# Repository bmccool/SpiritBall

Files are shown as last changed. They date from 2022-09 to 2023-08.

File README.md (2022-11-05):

---
tags: 📝️/🌱️
aliases:
  -
cssclass:
---

# TITLE: [[SpiritBall]]
---
## Demo

## Abstract
With 100 days until Christmas 2022, this project is set as a design challenge to create a Christmas decoration to be handed out as gifts, and as an excuse to learn and play with new tech toys and concepts.  This Readme is a copy of my notebook for this project.
## MOC
[[ESP32-S3]]
[[SpiritBall]]
[[KiCad]]
[[ESP Flasher]]
## Project Idea
- A Christmas ornament, or other holiday decoration in a ball form with addressable or patterned LED lighting.
- Primarily designed to be hung from a tree branch (plug in to light strand?)
- Based on [[ws812b]] LEDs.  
- Designed around multiple interlocking "leaves" and central management core.
	- See pic
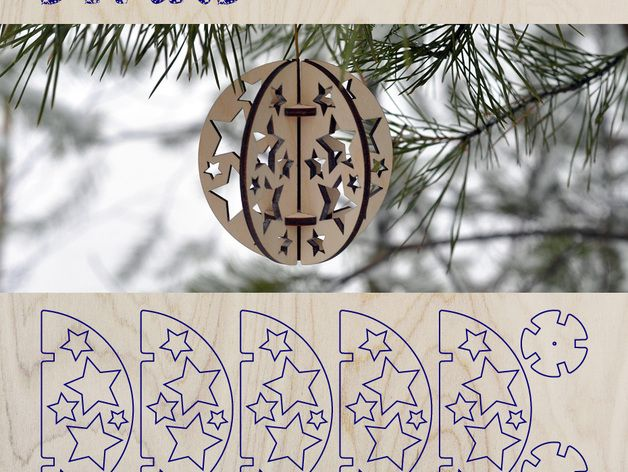
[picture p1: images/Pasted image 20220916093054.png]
		- 

## Design
### Mechanical
- Using the "multiple interlocking "leaves" strategy
	- Can we utilize card edge connectors?
	- Simpler, we could just leave the traces uncovered and solder bridge them together.
	- LEDs will be placed along the edge, firing normal to the leaf face.
		- First pass, only on one side, we can think about adding a second set on the reverse side later
		- LEDs should fire primarily in the direction of the next leaf, which should help with light diffusion
	- Do we need additional diffusion?
		- Likely not, given the LEDs will shine into the next leaf *AND* the abiliity of software to dim the LEDs, we shouldn't need mechanical diffusion
### Electrical
- Use a [[WS2812B]] [[SMD LEDs|LED]]
	- Likely this one, which I think is the same as on the ESP32-S3 Dev board
	- [WS2812B-Mini](https://jlcpcb.com/partdetail/Worldsemi-WS2812BMini/C527089)
	- Alternatively, this one which is the normal [[WS2812B]]
	- [WS2812B](https://jlcpcb.com/partdetail/Worldsemi-WS2812B_BW/C2761795)
- Control LEDs with [ESP32-S3 Module](https://jlcpcb.com/partdetail/3198296-ESP32_S3_WROOM_1N8/C2913198)
	- [Datasheet](https://www.espressif.com/sites/default/files/documentation/esp32-s3-wroom-1_wroom-1u_datasheet_en.pdf)
	- Likely need to spend some time figuring out how to use module standalone instead of on dev board
	- Can we power this from a standard christmas light strand?
		- How about a battery? 18650?
	- Technical things
		- EN/BOOT, Reset, Power On, UART/USB
			- A switch on EN would be a temporary contact to ground to reset the board, probably wanted on main board for a while
			- A siwtch on BOOT would allow the board to be reset into BOOTLOADER mode.  Which would then allow programming.  Assuming we are loading via USB/UART, which would otherwise control the EN and BOOT pins via transistors (see Automatic Bootloader for S3), we would never use this button.  Ergo, don't need it on board, we can pull a button (still not very useful) to the flash tool board to save space and parts.
			- So, onboard button for EN, no onboard button for BOOT, but we will utilize an external flash tool (usb/uart bridge) and we can stick a redundant EN button and BOOT button there.
			- In this scenario, we still need a pullup on EN.  BOOT can be left "floating" on the internal pullup.
- USB-C
	- [JLCPCB Link](https://jlcpcb.com/partdetail/Molex-1054500101/C134092)
	- [Molex Part](https://www.molex.com/molex/products/part-detail/io_connectors/1054500101)
	- [Molex Spec](https://www.molex.com/pdm_docs/ps/PS-105448-001-001.pdf)
	- USB/UART converter
### Software
## Work
- [[2022-09-26]] Created [SpiritBall Repo]() with first pass of schematic and PCB layout.  Tagging as [SpiritBall v0.1.0]()  This is intended as a minimum viable product with only a single plane of LEDs.  I still need to create board gerber files and run them through [[JLCPCB]] online tools to check for compatibility, as well as generate a BOM and place the order.
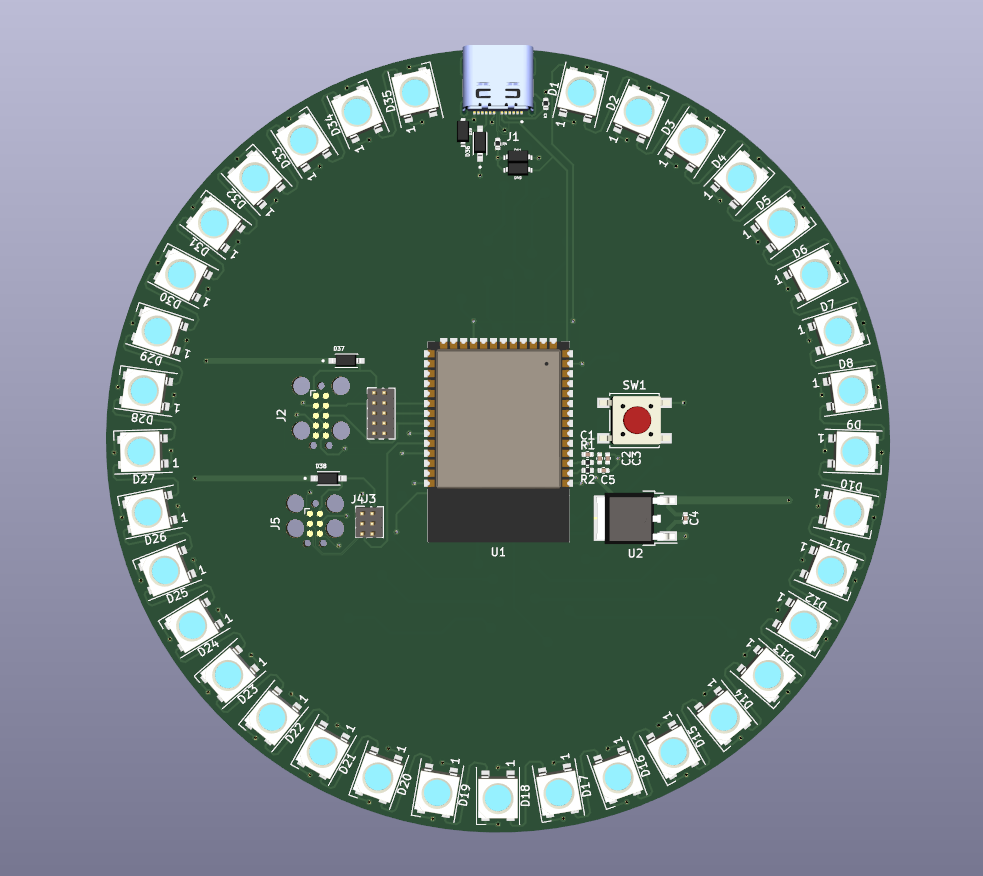
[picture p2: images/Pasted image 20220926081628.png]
	- 
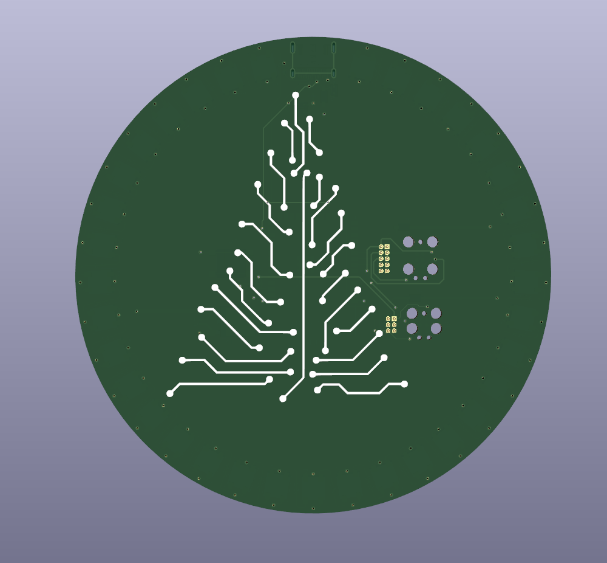
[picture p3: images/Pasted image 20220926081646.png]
	- 
- [[2022-11-01]] - Success!  The first batch of 5 assembled boards came back last week (I had done some minor tocuch up work, swapped some parts for in-stock, etc).  I also used a [[ESP-Prog]] flash board to get things started, though I think I could eventually use the USB cable or even [[OTA]] updates.  **TODO** add pictures and video.  Re: software, I've been turned onto using [[RMT]] for controlling the LEDs by [[@Chris Lomont]], and it was a cinch to get up and running a simple rainbow chase.  Now the fun part - Making it look more appealing and less like rainbow unicorn vomit :) 
	- PS: Had a brief moment of panic - Playing with some LED patterns and decided to pull back the brightness so it didn't hurt my eyes.  I lowered the SATURATION when I meant to lower the VALUE in the HVS color representation.  This of course just made all the LEDs white, and full brightness, which spiked current draw up over 700mA.  Oops.  But the program runs at boot, and is powered through the PROG interface meant there wasn't enough power available to flash through UART.  Turns out the USB port on the [[SpiritBall]] works fine to power the board with some extra power.  Plugged in both USB and PROG interface (which saw maybe 10mA draw) and recovered the board.  I'm pretty happy with how this first revision is performing.
	- Also, had to shake off some rust to get example code up and running.  Here's what I did:
		```
		cd C:\projects\brendon\ESP32S3-Project-Template
		xcopy /e /i C:\Espressif\frameworks\esp-idf-v5.0\examples\get-started\hello_world ./
		idf.py set-target esp32s3
		(remove build dir if it complains)
		idf.py -p COM5 flash monitor
		```
- [[2022-11-05]] - I've been experimenting with different patterns and have got to the point I have things worth saving.  So I'm spending some time to update github.  Also switched over to C++ for most things, but I kept the [[RMT]] encoder in C because I didn't feel like re-writing it and it works well enough as is... Maybe that's a task for a later date.  Things I still need to do:
	- [ ] Settle on a handful of set patterns (including `OFF`)
	- [ ] Cycle through set patterns with onboard buttons
	- [ ] Add some sort of software over-current protection
	- [ ] Update via USB-C cable
	- [ ] Update via OTA (stretch)
	- [ ] Control patterns via BT or WiFi (stretch)

/Work
# ./[[SpiritBall]]
---

Tags: [[ESP32-S3]]

Reference:

Related:

Created: [[2022-09-16]]

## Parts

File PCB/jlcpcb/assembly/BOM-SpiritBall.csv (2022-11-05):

Comment | Designator | Footprint | LCSC
105450-0101 | J1 | USB_C_MOLEX_105450-0101 | C134092
LESD5Z5.0CT1G | D39,D40,D41 | D_SOD-523 | C136167
0.1uF | C3 | C_0402_1005Metric | C1525
10uF | C2,C4 | C_0402_1005Metric | C15525
0k | R2 | R_0402_1005Metric | C17168
10K | R1,R5 | R_0402_1005Metric | C25744
5.1k | R3,R4 | R_0402_1005Metric | C25905
WS2812B | D1,D10,D11,D12,D13,D14,D15,D16,D17,D18,D19,D2,D20,D21,D22,D23,D24,D25,D26,D27,D28,D29,D3,D30,D31,D32,D33,D34,D35,D4,D5,D6,D7,D8,D9 | LED_WS2812B_PLCC4_5.0x5.0mm_P3.2mm | C2843785
ESP32-S3-WROOM-1 | U1 | ESP32-S3-WROOM-1 | C2913204
TS-1187A-B-A-B | SW1,SW2 | SW_TS-1187A-B-A-B | C318884
22uF | C5 | C_0402_1005Metric | C415703
AZ1117CD-3.3TRG1 | U2 | TO-252-2 | C460427
1uF | C1 | C_0402_1005Metric | C52923
1N5819HW-7-F | D36,D37,D38 | D_SOD-123 | C82544
1000uF | C6 | C_Elec_8x10.2 | C99833
TAG_CONNECT_DBG | J5 | Tag-Connect_TC2030-IDC-FP_2x03_P1.27mm_Vertical
TAG_CONNECT_JTAG | J2 | Tag-Connect_TC2050-IDC-FP_2x05_P1.27mm_Vertical
HEADER_DBG | J3 | PinHeader_2x03_P1.27mm_Vertical
HEADER_JTAG | J4 | PinHeader_2x05_P1.27mm_Vertical

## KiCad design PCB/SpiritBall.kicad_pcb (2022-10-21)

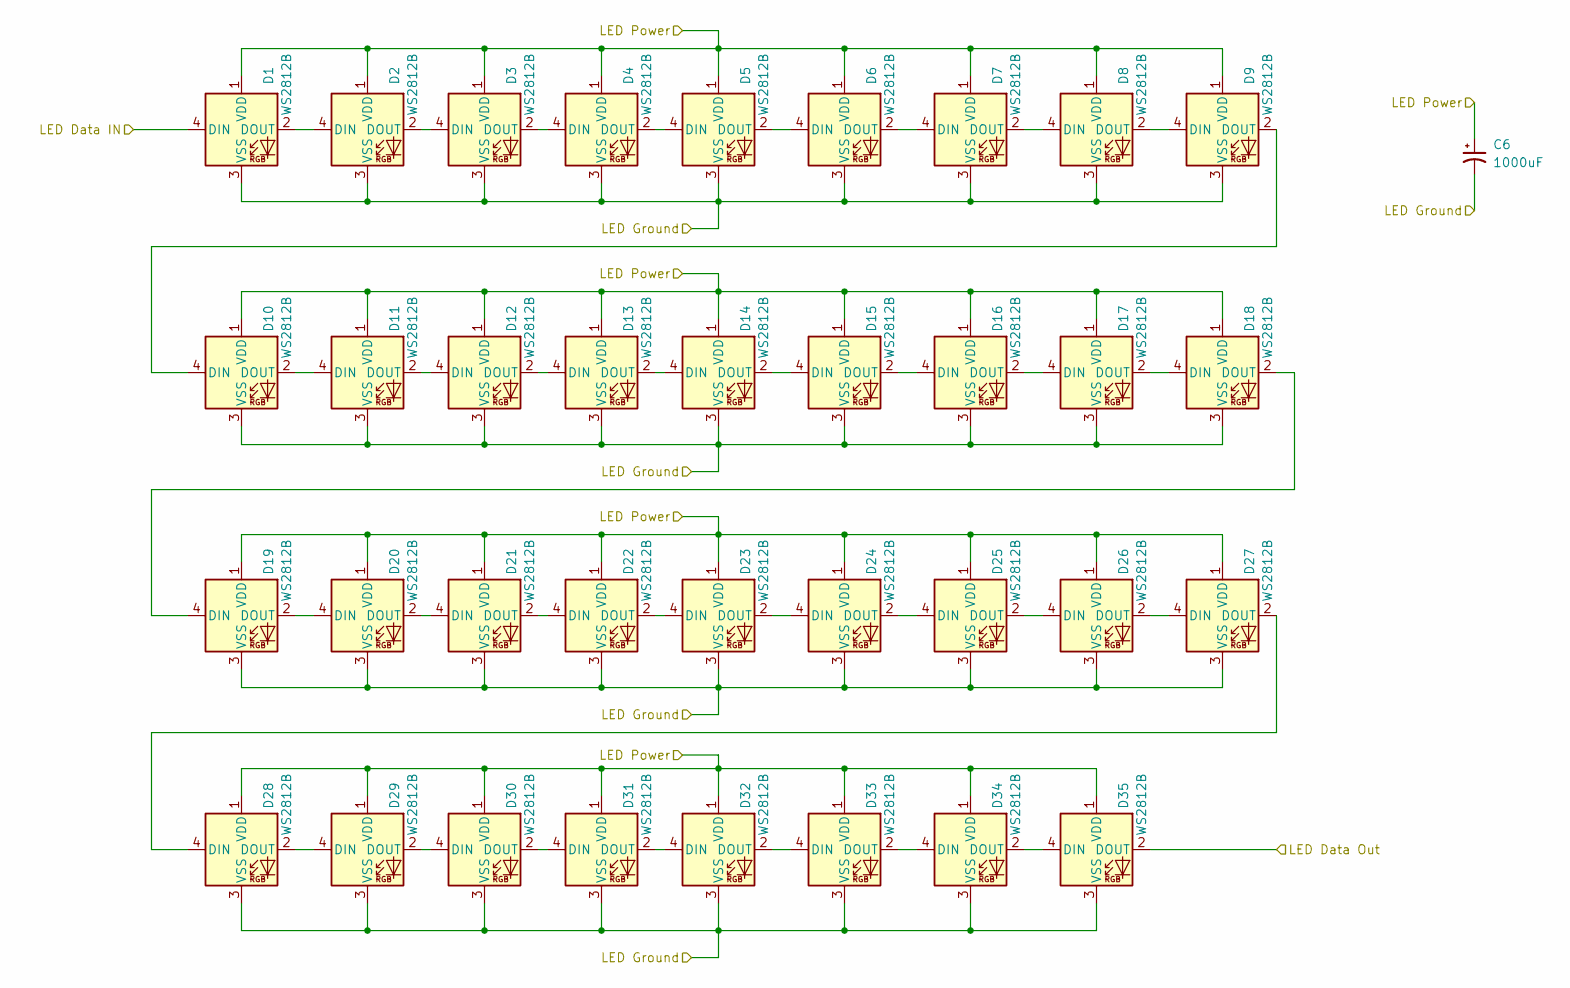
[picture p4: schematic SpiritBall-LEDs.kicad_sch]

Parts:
C6: 1000uF; C_Elec_8x10.2
D1, D2, D3, D4, D5, D6, D7, D8, D9, D10, D11, D12, D13, D14, D15, D16, D17, D18, D19, D20, D21, D22, D23, D24, D25, D26, D27, D28, D29, D30, D31, D32, D33, D34, D35: WS2812B; LED_WS2812B_PLCC4_5.0x5.0mm_P3.2mm

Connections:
+5V: C6.1, D1.1 (VDD), D2.1 (VDD), D3.1 (VDD), D4.1 (VDD), D5.1 (VDD), D6.1 (VDD), D7.1 (VDD), D8.1 (VDD), D9.1 (VDD), D10.1 (VDD), D11.1 (VDD), D12.1 (VDD), D13.1 (VDD), D14.1 (VDD), D15.1 (VDD), D16.1 (VDD), D17.1 (VDD), D18.1 (VDD), D19.1 (VDD), D20.1 (VDD), D21.1 (VDD), D22.1 (VDD), D23.1 (VDD), D24.1 (VDD), D25.1 (VDD), D26.1 (VDD), D27.1 (VDD), D28.1 (VDD), D29.1 (VDD), D30.1 (VDD), D31.1 (VDD), D32.1 (VDD), D33.1 (VDD), D34.1 (VDD), D35.1 (VDD); also elsewhere on the board
/ESP32-S3/LED Data: D1.4 (DIN); also elsewhere on the board
/LEDs/LED Data Out: D35.2 (DOUT)
GND: C6.2, D1.3 (VSS), D2.3 (VSS), D3.3 (VSS), D4.3 (VSS), D5.3 (VSS), D6.3 (VSS), D7.3 (VSS), D8.3 (VSS), D9.3 (VSS), D10.3 (VSS), D11.3 (VSS), D12.3 (VSS), D13.3 (VSS), D14.3 (VSS), D15.3 (VSS), D16.3 (VSS), D17.3 (VSS), D18.3 (VSS), D19.3 (VSS), D20.3 (VSS), D21.3 (VSS), D22.3 (VSS), D23.3 (VSS), D24.3 (VSS), D25.3 (VSS), D26.3 (VSS), D27.3 (VSS), D28.3 (VSS), D29.3 (VSS), D30.3 (VSS), D31.3 (VSS), D32.3 (VSS), D33.3 (VSS), D34.3 (VSS), D35.3 (VSS); also elsewhere on the board
unnamed: D1.2 (DOUT), D2.4 (DIN)
unnamed: D2.2 (DOUT), D3.4 (DIN)
unnamed: D3.2 (DOUT), D4.4 (DIN)
unnamed: D4.2 (DOUT), D5.4 (DIN)
unnamed: D5.2 (DOUT), D6.4 (DIN)
unnamed: D6.2 (DOUT), D7.4 (DIN)
unnamed: D7.2 (DOUT), D8.4 (DIN)
unnamed: D8.2 (DOUT), D9.4 (DIN)
unnamed: D10.2 (DOUT), D11.4 (DIN)
unnamed: D9.2 (DOUT), D10.4 (DIN)
unnamed: D11.2 (DOUT), D12.4 (DIN)
unnamed: D12.2 (DOUT), D13.4 (DIN)
unnamed: D13.2 (DOUT), D14.4 (DIN)
unnamed: D14.2 (DOUT), D15.4 (DIN)
unnamed: D15.2 (DOUT), D16.4 (DIN)
unnamed: D16.2 (DOUT), D17.4 (DIN)
unnamed: D17.2 (DOUT), D18.4 (DIN)
unnamed: D18.2 (DOUT), D19.4 (DIN)
unnamed: D19.2 (DOUT), D20.4 (DIN)
unnamed: D20.2 (DOUT), D21.4 (DIN)
unnamed: D21.2 (DOUT), D22.4 (DIN)
unnamed: D22.2 (DOUT), D23.4 (DIN)
unnamed: D23.2 (DOUT), D24.4 (DIN)
unnamed: D24.2 (DOUT), D25.4 (DIN)
unnamed: D25.2 (DOUT), D26.4 (DIN)
unnamed: D26.2 (DOUT), D27.4 (DIN)
unnamed: D27.2 (DOUT), D28.4 (DIN)
unnamed: D28.2 (DOUT), D29.4 (DIN)
unnamed: D29.2 (DOUT), D30.4 (DIN)
unnamed: D30.2 (DOUT), D31.4 (DIN)
unnamed: D31.2 (DOUT), D32.4 (DIN)
unnamed: D32.2 (DOUT), D33.4 (DIN)
unnamed: D33.2 (DOUT), D34.4 (DIN)
unnamed: D34.2 (DOUT), D35.4 (DIN)

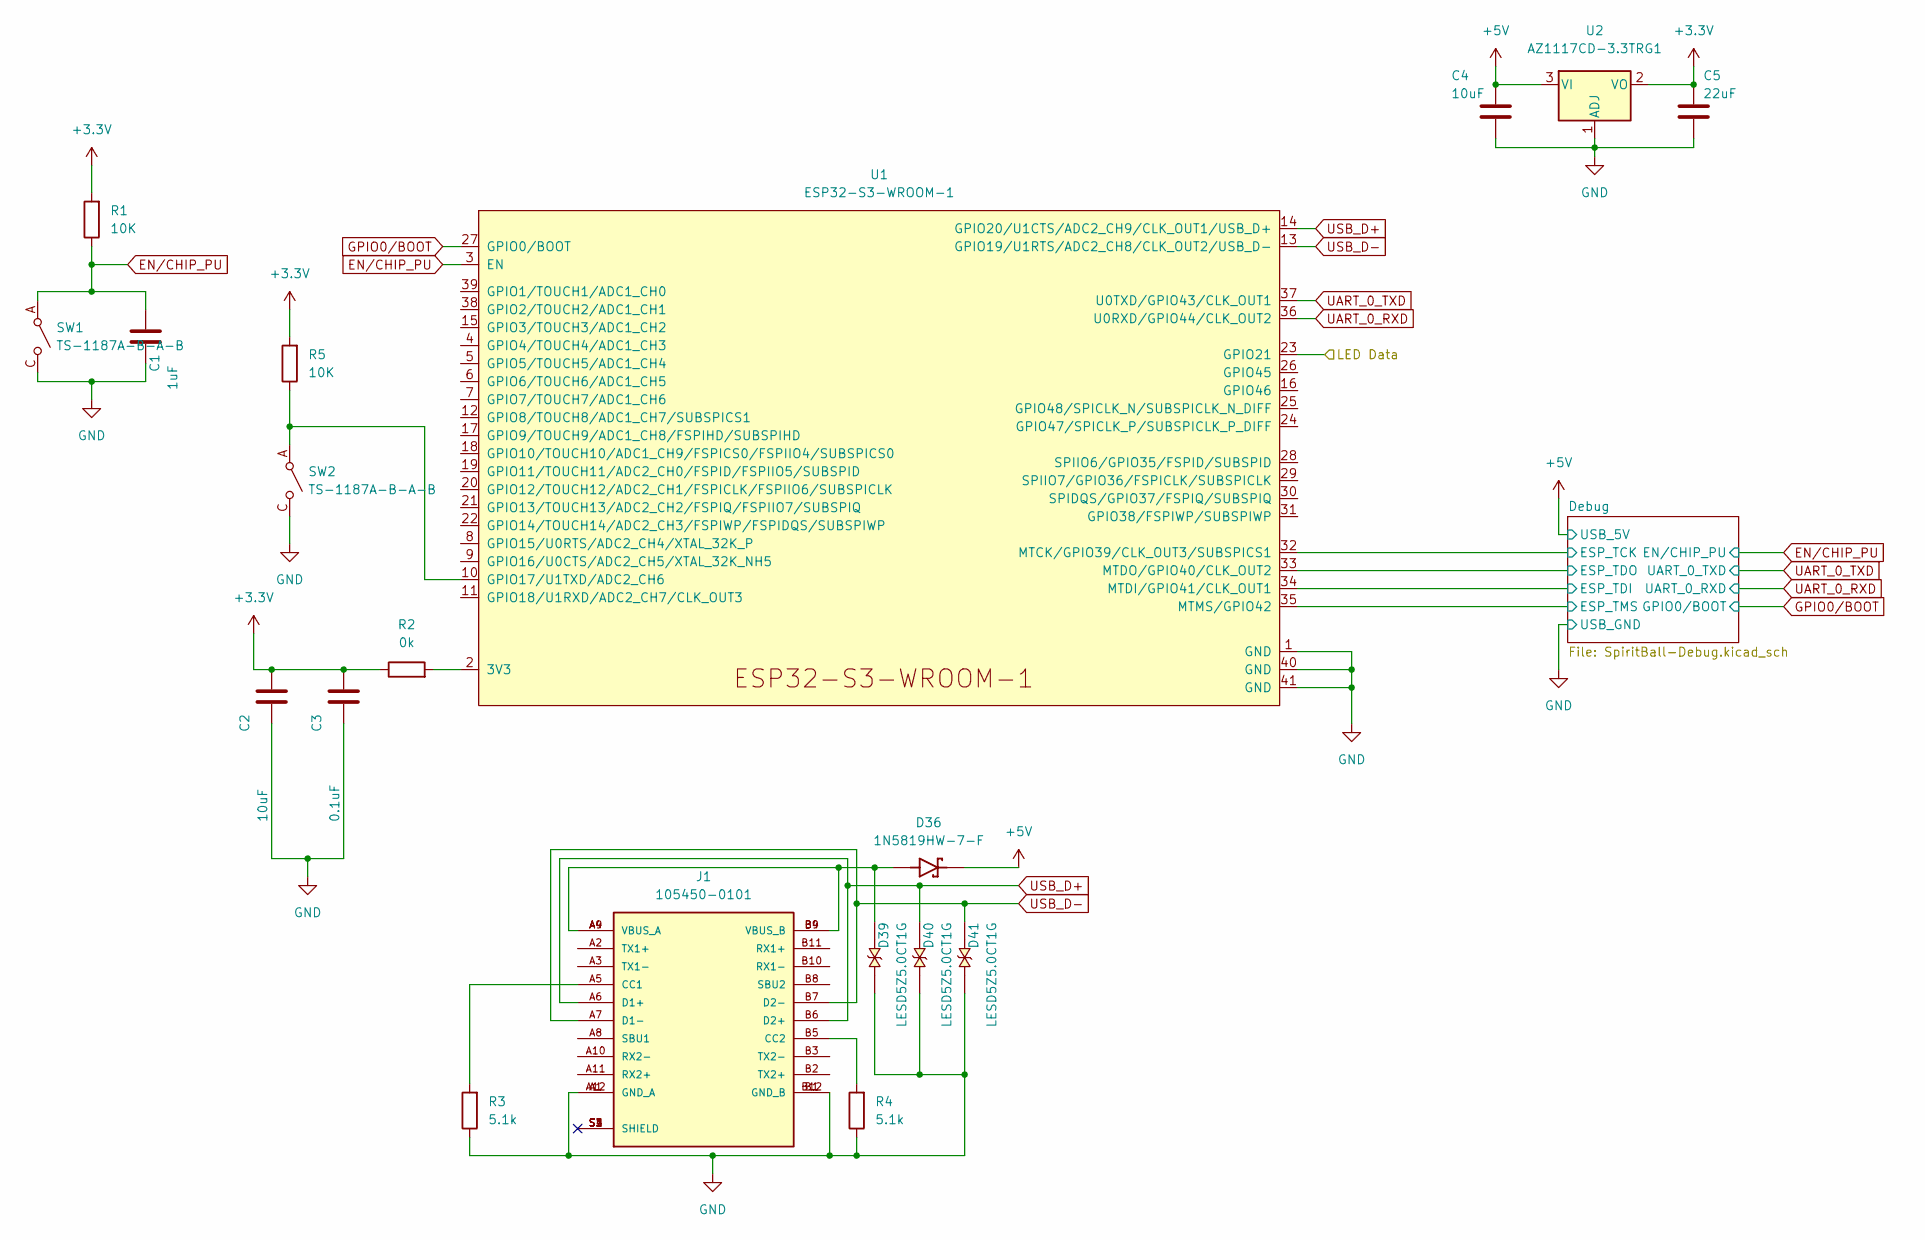
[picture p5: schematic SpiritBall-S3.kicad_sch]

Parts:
C1: 1uF; C_0402_1005Metric
C2, C4: 10uF; C_0402_1005Metric
C3: 0.1uF; C_0402_1005Metric
C5: 22uF; C_0402_1005Metric
D36: 1N5819HW-7-F; D_SOD-123; PARTREV 18-2
D39, D40, D41: LESD5Z5.0CT1G; D_SOD-523; PARTREV O
J1: 105450-0101; USB_C_MOLEX_105450-0101; PARTREV A7
R1, R5: 10K; R_0402_1005Metric
R2: 0k; R_0402_1005Metric
R3, R4: 5.1k; R_0402_1005Metric
SW1, SW2: TS-1187A-B-A-B; SW_TS-1187A-B-A-B
U1: ESP32-S3-WROOM-1
U2: AZ1117CD-3.3TRG1; TO-252-2

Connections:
+3.3V: C2.1, C3.1, C5.1, R1.2, R2.1, R5.2, U2.2 (VO)
+5V: C4.1, D36.1, U2.3 (VI); also elsewhere on the board
/ESP32-S3/Debug/ESP_TCK: U1.32 (MTCK/GPIO39/CLK_OUT3/SUBSPICS1); also elsewhere on the board
/ESP32-S3/Debug/ESP_TDI: U1.34 (MTDI/GPIO41/CLK_OUT1); also elsewhere on the board
/ESP32-S3/Debug/ESP_TDO: U1.33 (MTDO/GPIO40/CLK_OUT2); also elsewhere on the board
/ESP32-S3/Debug/ESP_TMS: U1.35 (MTMS/GPIO42); also elsewhere on the board
/ESP32-S3/LED Data: U1.23 (GPIO21); also elsewhere on the board
EN/CHIP_PU: C1.1, R1.1, SW1.A, SW1.B, U1.3 (EN); also elsewhere on the board
GND: C1.2, C2.2, C3.2, C4.2, C5.2, D39.1, D40.1, D41.1, J1.A1 (GND_A), J1.A12 (GND_A), J1.B1 (GND_B), J1.B12 (GND_B), R3.1, R4.1, SW1.C, SW1.D, SW2.C, SW2.D, U1.1 (GND), U1.40 (GND), U1.41 (GND), U2.1 (ADJ); also elsewhere on the board
GPIO0/BOOT: U1.27 (GPIO0/BOOT); also elsewhere on the board
unnamed: D36.2, D39.2, J1.A4 (VBUS_A), J1.A9 (VBUS_A), J1.B4 (VBUS_B), J1.B9 (VBUS_B)
unnamed: J1.A5 (CC1), R3.2
unnamed: J1.B5 (CC2), R4.2
unnamed: R2.2, U1.2 (3V3)
unnamed: R5.1, SW2.A, SW2.B, U1.10 (GPIO17/U1TXD/ADC2_CH6)
UART_0_RXD: U1.36 (U0RXD/GPIO44/CLK_OUT2); also elsewhere on the board
UART_0_TXD: U1.37 (U0TXD/GPIO43/CLK_OUT1); also elsewhere on the board
USB_D+: D40.2, J1.A6 (D1+), J1.B6 (D2+), U1.14 (GPIO20/U1CTS/ADC2_CH9/CLK_OUT1/USB_D+)
USB_D-: D41.2, J1.A7 (D1-), J1.B7 (D2-), U1.13 (GPIO19/U1RTS/ADC2_CH8/CLK_OUT2/USB_D-)

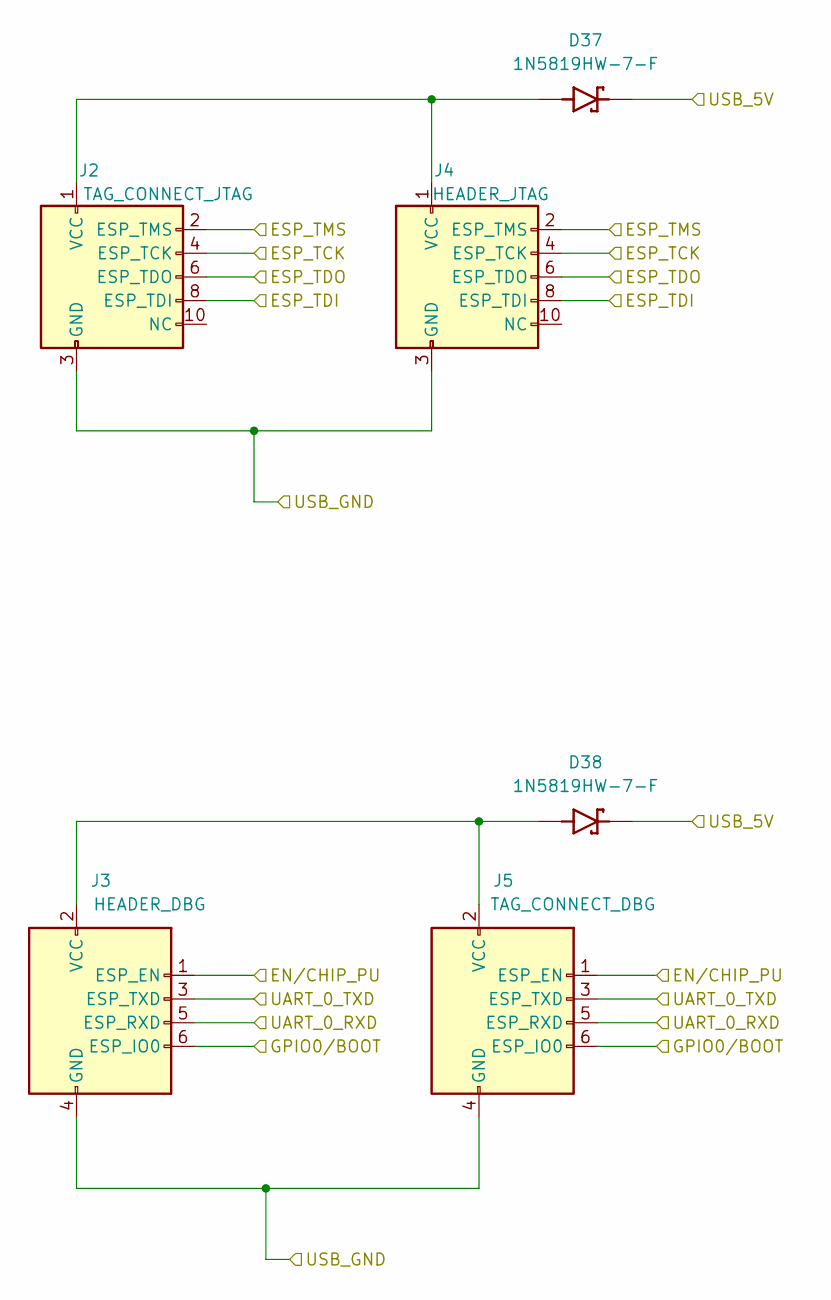
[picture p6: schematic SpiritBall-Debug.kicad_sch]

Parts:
D37, D38: 1N5819HW-7-F; D_SOD-123; PARTREV 18-2
J2: TAG_CONNECT_JTAG; Tag-Connect_TC2050-IDC-FP_2x05_P1.27mm_Vertical
J3: HEADER_DBG; PinHeader_2x03_P1.27mm_Vertical
J4: HEADER_JTAG; PinHeader_2x05_P1.27mm_Vertical
J5: TAG_CONNECT_DBG; Tag-Connect_TC2030-IDC-FP_2x03_P1.27mm_Vertical

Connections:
+5V: D37.1, D38.1; also elsewhere on the board
/ESP32-S3/Debug/ESP_TCK: J2.4 (ESP_TCK), J4.4 (ESP_TCK); also elsewhere on the board
/ESP32-S3/Debug/ESP_TDI: J2.8 (ESP_TDI), J4.8 (ESP_TDI); also elsewhere on the board
/ESP32-S3/Debug/ESP_TDO: J2.6 (ESP_TDO), J4.6 (ESP_TDO); also elsewhere on the board
/ESP32-S3/Debug/ESP_TMS: J2.2 (ESP_TMS), J4.2 (ESP_TMS); also elsewhere on the board
EN/CHIP_PU: J3.1 (ESP_EN), J5.1 (ESP_EN); also elsewhere on the board
GND: J2.3 (GND), J2.5 (GND), J2.7 (GND), J2.9 (GND), J3.4 (GND), J4.3 (GND), J4.5 (GND), J4.7 (GND), J4.9 (GND), J5.4 (GND); also elsewhere on the board
GPIO0/BOOT: J3.6 (ESP_IO0), J5.6 (ESP_IO0); also elsewhere on the board
unnamed: D37.2, J2.1 (VCC), J4.1 (VCC)
unnamed: D38.2, J3.2 (VCC), J5.2 (VCC)
UART_0_RXD: J3.5 (ESP_RXD), J5.5 (ESP_RXD); also elsewhere on the board
UART_0_TXD: J3.3 (ESP_TXD), J5.3 (ESP_TXD); also elsewhere on the board

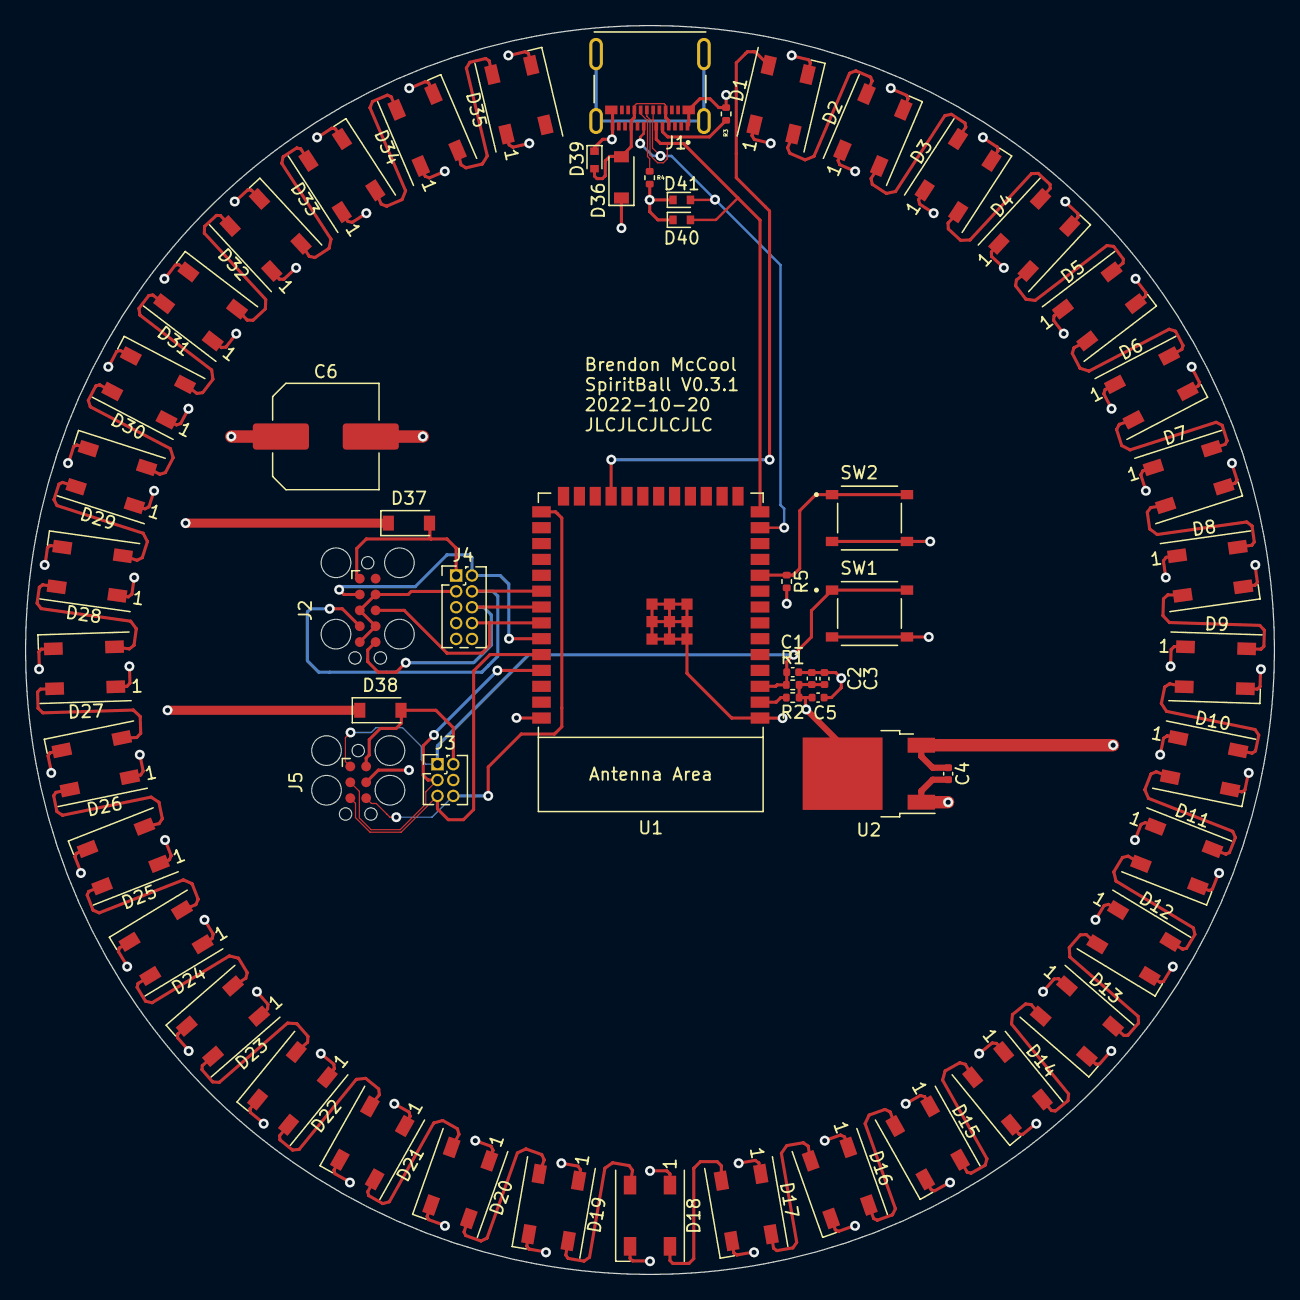
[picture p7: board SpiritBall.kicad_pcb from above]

Board: 4 copper layers, 100.0 x 100.0 mm, 61 parts (0 on the bottom side), 55 nets.

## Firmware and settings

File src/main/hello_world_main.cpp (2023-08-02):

/*
 * SPDX-FileCopyrightText: 2010-2022 Espressif Systems (Shanghai) CO LTD
 *
 * SPDX-License-Identifier: CC0-1.0
 */

#include <stdio.h>
#include <iostream> // cin, cout
#include <string.h> /* memset */
#include "sdkconfig.h"
#include "freertos/FreeRTOS.h"
#include "freertos/task.h"
#include "freertos/queue.h" // QueueHandle_t
#include "esp_chip_info.h"
#include "esp_flash.h"
#include "driver/rmt_tx.h"
#include "driver/gpio.h"

#include "led/led_strip_encoder.h"
#include "McCoolLEDs.hpp"


//#include "McCoolLEDs.h"


#define RMT_LED_STRIP_RESOLUTION_HZ 10000000 // 10MHz resolution, 1 tick = 0.1us (led strip needs a high resolution)
#define RMT_LED_STRIP_GPIO_NUM      (gpio_num_t)21
#define GPIO_INPUT_BUTTON_SW2       (gpio_num_t)17
#define GPIO_INPUT_PIN_SEL  ((1ULL<<GPIO_INPUT_BUTTON_SW2))

#define EXAMPLE_LED_NUMBERS         35
#define EXAMPLE_CHASE_SPEED_MS      10
#define ESP_INTR_FLAG_DEFAULT       0
#define NUM_PATTERNS                5
static const char *TAG = "example";

#include "esp_check.h"

extern "C" {
    void app_main();
}

static int loop_state = 0;


static uint8_t led_strip_pixels[EXAMPLE_LED_NUMBERS * 3];

void glow_random(rmt_channel_handle_t channel, rmt_encoder_t *encoder, const rmt_transmit_config_t *config){
    //uint16_t speed_ms = 100;
    McCoolLEDClump clump(channel, encoder, config, 35);
    ESP_LOGI(TAG, "Start LED Glow Random with CLUMP");
    while (1) {
        //std::cout << "clump.glow_random()" << std::endl;
        clump.glow_random_2(10, 10, 100); // Flush RGB values to LEDs
        //vTaskDelay(pdMS_TO_TICKS(speed_ms));
        vTaskDelay(pdMS_TO_TICKS(100));
    }
}

void pattern_loop(rmt_channel_handle_t channel, rmt_encoder_t *encoder, const rmt_transmit_config_t *config){
    //uint16_t speed_ms = 100;
    McCoolLEDClump clump(channel, encoder, config, 35);
    ESP_LOGI(TAG, "Starting Pattern Loop with CLUMP");

    //int pattern = 1;
    while (1) {
        switch(loop_state){
            case 3:
                clump.glow_random_2(10, 10, 100);
                vTaskDelay(pdMS_TO_TICKS(100)); // 0 for no delay, still needed to reschedule
                break;
            case 1:
                clump.rainbow_chase();
                vTaskDelay(pdMS_TO_TICKS(0)); // 0 for no delay, still needed to reschedule
                break;
            case 2:
                clump.glow_as_one(35, 10, 100);
                vTaskDelay(pdMS_TO_TICKS(100)); // 0 for no delay, still needed to reschedule
                break;
            case 5:
                clump.chase(1, 3);
                vTaskDelay(pdMS_TO_TICKS(40)); // 0 for no delay, still needed to reschedule
                break;
            case 4:
                clump.chase_colorized(2, 4, christmas);
                vTaskDelay(pdMS_TO_TICKS(40)); // 0 for no delay, still needed to reschedule
                break;
            case 0:
                clump.glow_tranistion_naive(christmas);
                vTaskDelay(pdMS_TO_TICKS(10)); // 0 for no delay, still needed to reschedule
                break;
            default:
                if (loop_state >= 100){
                    std::cout << "Resetting Loop" << std::endl;
                    clump.reset();
                    loop_state -= 100;
                }
                if (loop_state < 0){ loop_state = 0; }
                break;
        }
        
    }
}

//// GPIO
static QueueHandle_t gpio_evt_queue = NULL;

static void IRAM_ATTR gpio_isr_handler(void* arg)
{
    uint32_t gpio_num = (uint32_t) arg;
    xQueueSendFromISR(gpio_evt_queue, &gpio_num, NULL);
}

static void gpio_task(void* arg)
{
    uint32_t io_num;
    for(;;) {
        if(xQueueReceive(gpio_evt_queue, &io_num, portMAX_DELAY)) {
            if (gpio_get_level((gpio_num_t)io_num) == 1){
                loop_state += 1;
                if (loop_state > NUM_PATTERNS){
                    loop_state = 0;
                }
                // 100 signifies need to reset TODO make this a state machine please!
                if (loop_state < 100){
                    loop_state += 100;
                }
            }
            std::cout << "GPIO[" << io_num << "] interrupt, value: " << gpio_get_level((gpio_num_t)io_num) << ",  loop_state = " << loop_state << std::endl;
        }
    }
}

void setup_gpio_inputs(uint64_t pin_sel){
    //zero-initialize the config structure.
    gpio_config_t io_conf = {};

    //interrupt of rising edge
    io_conf.intr_type = GPIO_INTR_ANYEDGE;
    //bit mask of the pins
    io_conf.pin_bit_mask = pin_sel;
    //set as input mode
    io_conf.mode = GPIO_MODE_INPUT;
    //disable pull-up mode
    io_conf.pull_up_en = GPIO_PULLUP_DISABLE;
    //disable pull-down mode
    io_conf.pull_down_en = GPIO_PULLDOWN_DISABLE;
    gpio_config(&io_conf);

    //create a queue to handle gpio event from isr
    gpio_evt_queue = xQueueCreate(10, sizeof(uint32_t));
    //start gpio task
    xTaskCreate(gpio_task, "gpio_task", 2048, NULL, 10, NULL);

    //install gpio isr service
    gpio_install_isr_service(ESP_INTR_FLAG_DEFAULT);
    //hook isr handler for specific gpio pin
    gpio_isr_handler_add(GPIO_INPUT_BUTTON_SW2, gpio_isr_handler, (void*) GPIO_INPUT_BUTTON_SW2);
    //remove isr handler for gpio number.
    //gpio_isr_handler_remove(GPIO_INPUT_IO_0);
}

/// END GPIO

void app_main(void)
{

    ESP_LOGI(TAG, "Setting up GPIO");
    setup_gpio_inputs(GPIO_INPUT_PIN_SEL);

    ESP_LOGI(TAG, "Create RMT TX channel");
    rmt_channel_handle_t led_chan = NULL;
    rmt_tx_channel_config_t tx_chan_config = {
        .gpio_num = RMT_LED_STRIP_GPIO_NUM,
        .clk_src = RMT_CLK_SRC_DEFAULT, // select source clock
        .resolution_hz = RMT_LED_STRIP_RESOLUTION_HZ,
        .mem_block_symbols = 64, // increase the block size can make the LED less flickering
        .trans_queue_depth = 4, // set the number of transactions that can be pending in the background
        .flags = { 0, 0, 0, 0 }
    };
    ESP_ERROR_CHECK(rmt_new_tx_channel(&tx_chan_config, &led_chan));

    ESP_LOGI(TAG, "Install led strip encoder");
    rmt_encoder_handle_t led_encoder = NULL;
    led_strip_encoder_config_t encoder_config = {
        .resolution = RMT_LED_STRIP_RESOLUTION_HZ,
    };
    ESP_ERROR_CHECK(rmt_new_led_strip_encoder(&encoder_config, &led_encoder));

    ESP_LOGI(TAG, "Enable RMT TX channel");
    ESP_ERROR_CHECK(rmt_enable(led_chan));

    rmt_transmit_config_t tx_config = {
        .loop_count = 0, // no transfer loop
        .flags = { 0 }
    };

    //chase(led_chan, led_encoder, &tx_config);
    //line(led_chan, led_encoder, &tx_config);
    //glow_as_one(led_chan, led_encoder, &tx_config);
    //glow_random(led_chan, led_encoder, &tx_config);
    pattern_loop(led_chan, led_encoder, &tx_config);

    printf("Hello world!\n");

    /* Print chip information */
    esp_chip_info_t chip_info;
    uint32_t flash_size;
    esp_chip_info(&chip_info);
    printf("This is %s chip with %d CPU core(s), WiFi%s%s, ",
           CONFIG_IDF_TARGET,
           chip_info.cores,
           (chip_info.features & CHIP_FEATURE_BT) ? "/BT" : "",
           (chip_info.features & CHIP_FEATURE_BLE) ? "/BLE" : "");

    printf("silicon revision %d, ", chip_info.revision);
    if(esp_flash_get_size(NULL, &flash_size) != ESP_OK) {
        printf("Get flash size failed");
        return;
    }

    printf("%uMB %s flash\n", flash_size / (1024 * 1024),
           (chip_info.features & CHIP_FEATURE_EMB_FLASH) ? "embedded" : "external");

    printf("Minimum free heap size: %d bytes\n", esp_get_minimum_free_heap_size());

    for (int i = 10; i >= 0; i--) {
        printf("Restarting in %d seconds...\n", i);
        vTaskDelay(1000 / portTICK_PERIOD_MS);
    }
    printf("Restarting now.\n");
    fflush(stdout);
    esp_restart();
}

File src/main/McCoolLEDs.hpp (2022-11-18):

#pragma once
#include <stdint.h>
#include <cstdlib> // rand
#include <vector> // std::vector
#include <string.h> /* memset */
#include <iostream> // cin, cout
#include "driver/rmt_tx.h" // TODO/ I'd rather this file not know about the driver implementation...
#include <set>

// COLOR DEFINES
#define BLUE {0, 100, 0}         // 360/0 Blue
#define CYAN {60, 100, 0}        // 60 Cyan
#define GREEN {120, 100, 0}      // 120
#define YELLOW {180, 100, 0}     // 180 yellowgreen
#define RED {240, 100, 0}        // 240 red
#define PURPLE {300, 100, 0}     // 300 Purple



/**
 * @brief Simple helper function, converting HSV color space to RGB color space
 *
 * Wiki: https://en.wikipedia.org/wiki/HSL_and_HSV
 *
 */
void led_strip_hsv2rgb(uint32_t h, uint32_t s, uint32_t v, uint32_t *r, uint32_t *g, uint32_t *b)
{
    h %= 360; // h -> [0,360]
    uint32_t rgb_max = v * 2.55f;
    uint32_t rgb_min = rgb_max * (100 - s) / 100.0f;

    uint32_t i = h / 60;
    uint32_t diff = h % 60;

    // RGB adjustment amount by hue
    uint32_t rgb_adj = (rgb_max - rgb_min) * diff / 60;

    switch (i) {
    case 0:
        *r = rgb_max;
        *g = rgb_min + rgb_adj;
        *b = rgb_min;
        break;
    case 1:
        *r = rgb_max - rgb_adj;
        *g = rgb_max;
        *b = rgb_min;
        break;
    case 2:
        *r = rgb_min;
        *g = rgb_max;
        *b = rgb_min + rgb_adj;
        break;
    case 3:
        *r = rgb_min;
        *g = rgb_max - rgb_adj;
        *b = rgb_max;
        break;
    case 4:
        *r = rgb_min + rgb_adj;
        *g = rgb_min;
        *b = rgb_max;
        break;
    default:
        *r = rgb_max;
        *g = rgb_min;
        *b = rgb_max - rgb_adj;
        break;
    }
}

void rgb2hsv(uint32_t r, uint32_t g, uint32_t b, uint16_t *h, uint16_t *s, uint16_t *v)
{
    float r_prime = r/255;
    float g_prime = g/255;
    float b_prime = b/255;

    float cmax = r_prime;
    float cmin = r_prime;
    float delta;
    if (g_prime > cmax){
        cmax = g_prime;
    }
    if (g_prime < cmin){
        cmin = g_prime;
    }
    if (b_prime > cmax){
        cmax = b_prime;
    }
    if (b_prime < cmin){
        cmin = b_prime;
    }
    delta = cmax - cmin;
    if (delta == 0){
        *h = 0;
    }
    else if (cmax == r_prime){
        *h = 60 * (int((g_prime - b_prime) / delta) % 6);
    }
    else if (cmax == g_prime){
        *h = 60 * (((b_prime - r_prime) / delta) + 2);
    }
    else { // cmax == b_prime
        *h = 60 * (((r_prime - g_prime) / delta) + 4);
    }

    if (cmax == 0){
        *s = 0;
    }
    else {
        *s = delta / cmax;
    }

    *v = cmax;
    // TODO my hue is shifted by a bit...
    *h = (*h - 60) % 360;
}


struct ColorHSV
{
    uint16_t hue;
    uint16_t saturation;
    uint16_t value;
};

struct ColorRGB
{
    uint16_t red;
    uint16_t green;
    uint16_t blue;
};

static const std::vector<ColorHSV> christmas = {RED, GREEN};

class McCoolLED {
    private:
        
    public:
        uint16_t hue;
        uint16_t saturation;
        uint16_t value;

        uint32_t red = 0;
        uint32_t green = 0;
        uint32_t blue = 0;

        uint16_t ttl_ticks; // Time To Live
        uint16_t tl_ticks;  // Time Lived
        int16_t hue_trajectory;
        bool is_alive;

        uint16_t position;
        // xyz?
        //std::vector<ColorHSV> christmas = {RED, GREEN};
        // 360/0 Blue
        // 60 Cyan
        // 120
        // 180 yellowgreen
        // 240 red
        // 300 Purple

        // Pattern
        int pattern_position = 0;
        




        McCoolLED(uint16_t hue, uint16_t saturation, uint16_t value, uint16_t ttl_ticks, int16_t hue_trajectory, uint16_t position): hue(hue), saturation(saturation), value(value), ttl_ticks(ttl_ticks), hue_trajectory(hue_trajectory), position(position){ is_alive = true; tl_ticks = 0;}

        bool glow(){
            if(is_alive == false){ return(false); }
            if(tl_ticks < (ttl_ticks / 2)){
                // Glowing Brighter
                value += 1;
            }
            else{
                // Glowing Dimmer
                value -= 1;
            }
            tl_ticks += 1;

            if(tl_ticks > ttl_ticks){
                is_alive = false;
            }
            return(true);
        }

        bool chase(){
            if(is_alive == false){ return(false); }
            tl_ticks += 1;
            if(tl_ticks >= ttl_ticks){
                is_alive = false;
            }
            return(true);
        }

        bool naive_transition(void){
            // Just go to the next color in the pattern
            // Only worry about hue and saturation for now, leave value at whatever it is already set at.

            //uint32_t targetr;
            //uint32_t targetg;
            //uint32_t targetb;

            int target;
            float percent_complete;

            target = pattern_position + 1;
            if (target >= christmas.size()){
                target = 0;
            }
            //std::cout << "Target is " << target << ".  ";

            //std::cout << "Difference: " << (christmas[target].hue - hue + 360) % 360 << ".  ";
            if (((christmas[target].hue - hue + 360) % 360) < 180){
                // Move in positive hue direction
                //std::cout << "Moving in the positive direction.  ";
                if (hue == 360) { hue = 0; }
                hue += 1;
                if (hue > christmas[target].hue) { hue = christmas[target].hue; }
            } else {
                // Move in negative hue direction
                //std::cout << "Moving in the negative direction.  ";
                if (hue == 0) { hue = 360; }
                hue -= 1;
                if (hue < christmas[target].hue) { hue = christmas[target].hue; }
            }

            //std::cout << "Hue: " << hue << std::endl;
            percent_complete = 100 * (float)abs(christmas[pattern_position].hue - hue) / abs(christmas[pattern_position].hue - christmas[target].hue);
            //std::cout << "Percent Complete: " << percent_complete << std::endl;
            //value = (percent_complete / 100 * 10);
            value = 10 * ((percent_complete - 50) * (percent_complete - 50)) / 2500;
            if (hue == christmas[target].hue){ return true; }
            return false;
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

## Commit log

2022-09-26 Add readme, move pcb files to subfolder
    [SpiritBall-Debug.kicad_sch, SpiritBall-LEDs.kicad_sch, SpiritBall-S3.kicad_sch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]
2022-10-21 Version 0.3.0, sent for fabrication
    [SpiritBall-Debug.kicad_sch, SpiritBall-LEDs.kicad_sch, SpiritBall-S3.kicad_sch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]
2022-11-05 Update PCB files for v0.3.0
    [BOM-SpiritBall.csv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]
2022-11-08 Add button, two total patterns
